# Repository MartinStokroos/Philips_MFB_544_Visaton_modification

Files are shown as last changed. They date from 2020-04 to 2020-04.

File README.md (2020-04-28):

# Squawker and Tweeter Modification for the Philips 544 MFB Speaker

This repository contains design information of 3D printable adapter parts to replace the original midrange and high frequency driver from the Philips 22RH544 MFB speaker with Visaton drivers. Feel free to fork this project to improve this modification proposal.

ORIGINAL 544 | MODIFIED 544 | BEST COMPROMISE
------------ | ------------ | ---------------
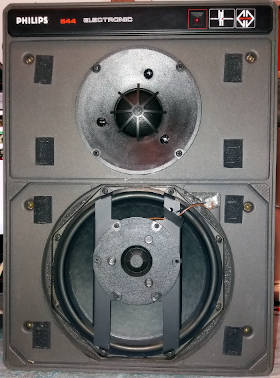
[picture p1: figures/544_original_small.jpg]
Philips 22RH544
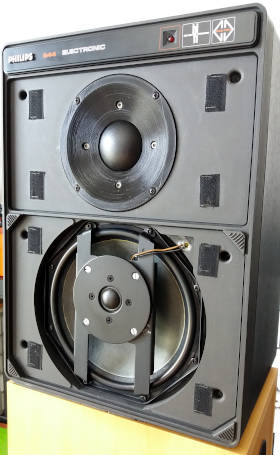
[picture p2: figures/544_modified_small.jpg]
Modified 544
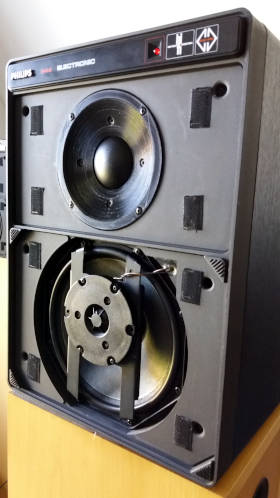
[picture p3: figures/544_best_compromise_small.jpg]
Best compromise 544
 |  | 

The following driver substitutes were selected because of their attractive price, quality and form-factor, which comes the closest to the original drivers:

PHILIPS | VISATON
------- | -------
Squawker AD0211/SQ8 | Visaton G 50 FFL dome midrange [1]
Tweeter AD0163/TE8 | Visaton G 20 SC dome tweeter [2]

## Why upgrading?
- The Philips AD0211/Sq8 squawker most often fails and a replacement must be found [3], [4].
- Overall improvement of the sound quality of the midrange and high frequencies.

## Conclusion
Attempt #3 seems the best compromise. It is the combination of the Visaton G50FFL soft dome midrange driver with the new baffle/horn design and the original Philips AD0163 tweeter. The provided solution solves the problem for a broken AD0211.
The frequency response is very close to the original. Minimal modifications of the electronics is needed in the 22RH544/50R. 

## Design for 3D-printed parts
Modification Attempt | openSCAD files | Remarks
-------------------- | -------------- | -------
 #1 | G50FFL_spacer_v1.scad G20SC_spacer_v1.scad | Mid driver sticks out above the baffle causing(?) a worse dip in the frequency reponse around 1.8kHz. The tweeter spacer does not need extra fixation holes to be drilled in the brackets. M4 hex-nuts can be pressed into the holes intended for mounting the tweeter on top of the spacer ring.  (3D-print with support on). The dust covers can not be put back, because the driver domes are sticking too far outside. 
 #2 | G50FFL_baffle_v1.scad G20SC_spacer_v2.scad | Attempt two with a new baffle/horn design for the G50FFL. (3D-print with support on). The dome is placed inwards to the original position of the AD0211 dome. The metal flange of the G50FFL must be removed by removing the four screws from the front side. The extra gasket, included with the G50FFL package, must be used between the driver and the new baffle/horn. The tweeter has been replaced by the G20SC and has been placed deeper inwards too. It is mounted with a 2mm spacer ring, leaving enough room for extreme woofer excursions. Fixation holes must be drilled in the brackets for mounting. The dust covers can be put back on. A small dip in the frequency response has been observed around the mid/high crossover frequency (~5kHz).
 #3 | G50FFL_baffle_v1.scad | The squawker AD0211 has been replaced by the G50FFL with the new baffle/horn design as in attempt #2. The original AD0136 tweeter has been restored.  The midrange frequencies around 1kHz are elevated a few dB's compared to the original. A minor modification in the electronics solves this problem.
Bonus | 544_capstand.scad | Capacitor mount, see pictures below. 

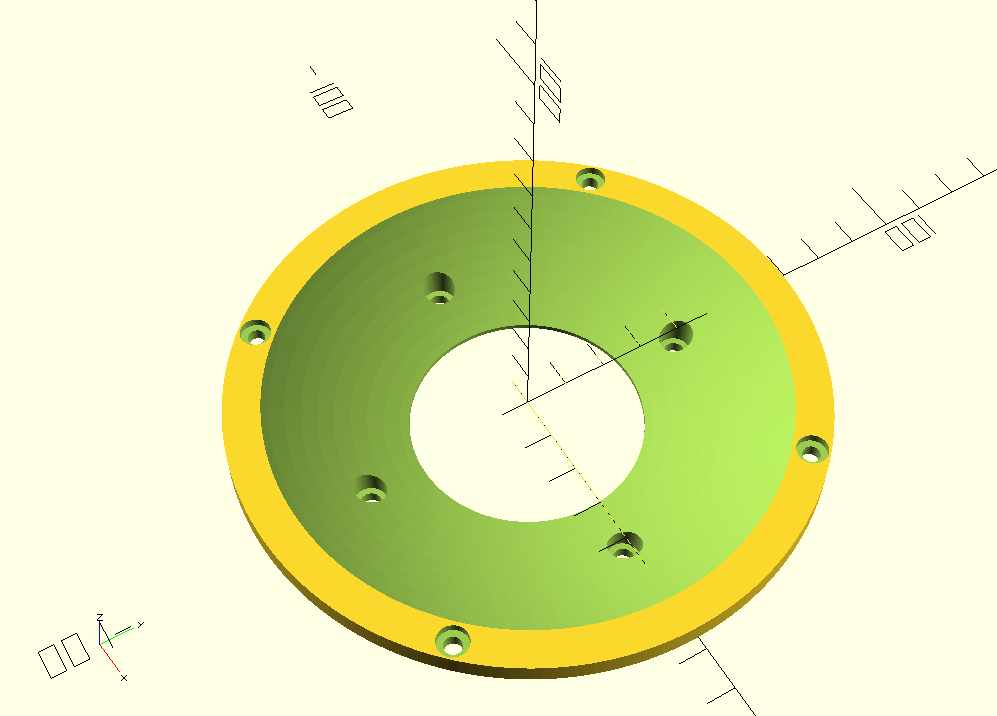
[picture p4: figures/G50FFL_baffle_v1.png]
new G50FFL baffle new G50FFL baffle_v1
# 

## Assembly
### G50FFL baffle
Push the washers (M4) into the holes. | Remove the flange from the Visaton G50FFL carefully.
------------------------------------ | ---------------------------------------------------
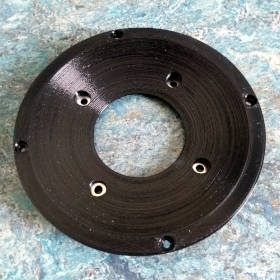
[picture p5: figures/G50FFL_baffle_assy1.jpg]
assy step 1
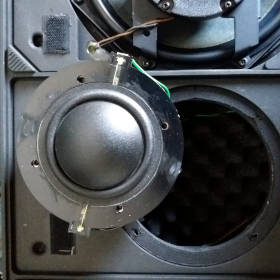
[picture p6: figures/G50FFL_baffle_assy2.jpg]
assy step 2
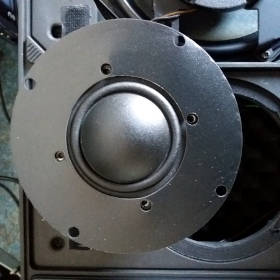
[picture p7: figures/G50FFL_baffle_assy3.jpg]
assy step 3
 |  | 

Place the spare gasket. | Mount the baffle and cutaway the redundant gasket material. Use M4*10mm screws with cylinder head.
---------------------- | ----------------------------------------------------------
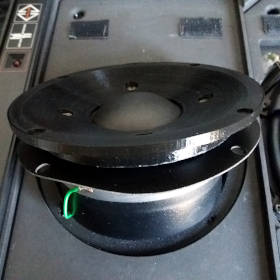
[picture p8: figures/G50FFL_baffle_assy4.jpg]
assy step 4
assy step 3 | 

| Mount the completed driver assembly. | 
| ----------------------------------- |
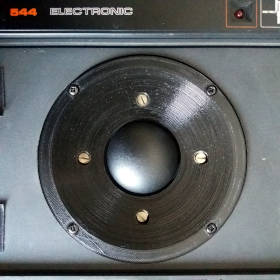
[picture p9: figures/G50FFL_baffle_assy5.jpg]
assy step 5
|  |

### Capacitor mount
BEFORE | AFTER
------ | -----
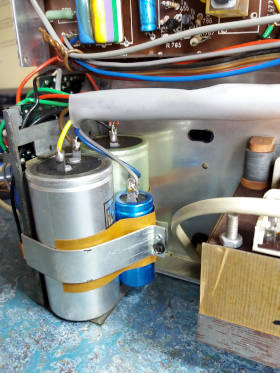
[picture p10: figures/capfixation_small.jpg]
original mount Capacitor fixation
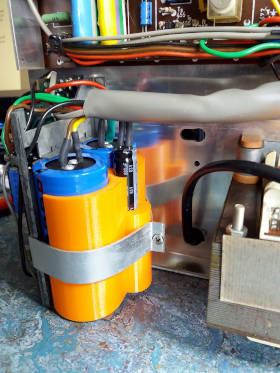
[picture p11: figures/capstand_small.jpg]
modified mount Capacitor stand
 | 
 
Recommended capacitors:

* C588, C535 = 4700 μF/63V, Vishay BCcomponents, 058/059 PLL-SI series aluminium capacitors, radial snap in 35 mm. (Conrad article #446251)
* C565 = 680 μF/40V, Panasonic EEU-FR1J681L series, radial 12.5 mm. (Conrad article #1476134)

## Modification of the electronics
To approach the original frequency response with modification attempt #3, the following changes should be made in the electronics of the 22RH544/50R:

* The frequency correction network consisting of R730 and C567 from the crossover network, should be disabled by removing R730.
* An L-pad network consisting of an 1.2 Ohms series resistor and a 47 Ohms parallel resistor should be placed between the crossover filter and the G50FFL driver (S405). This will add 1.5dB attenuation for the midrange.

| The 544 crossover network. In /50R, C568=3.3μF. |
| ----------------------------------------------- |
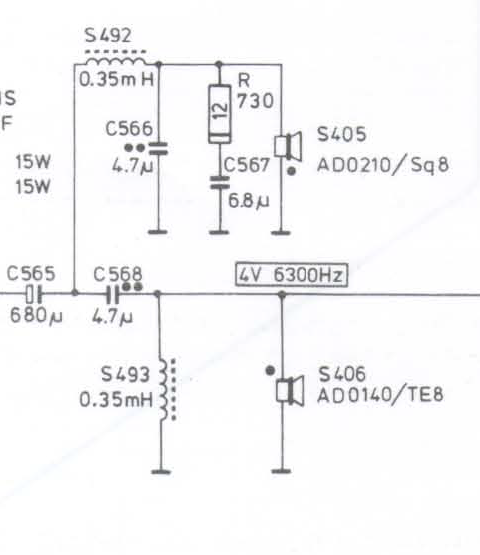
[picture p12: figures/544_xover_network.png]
544 crossover network
|  |
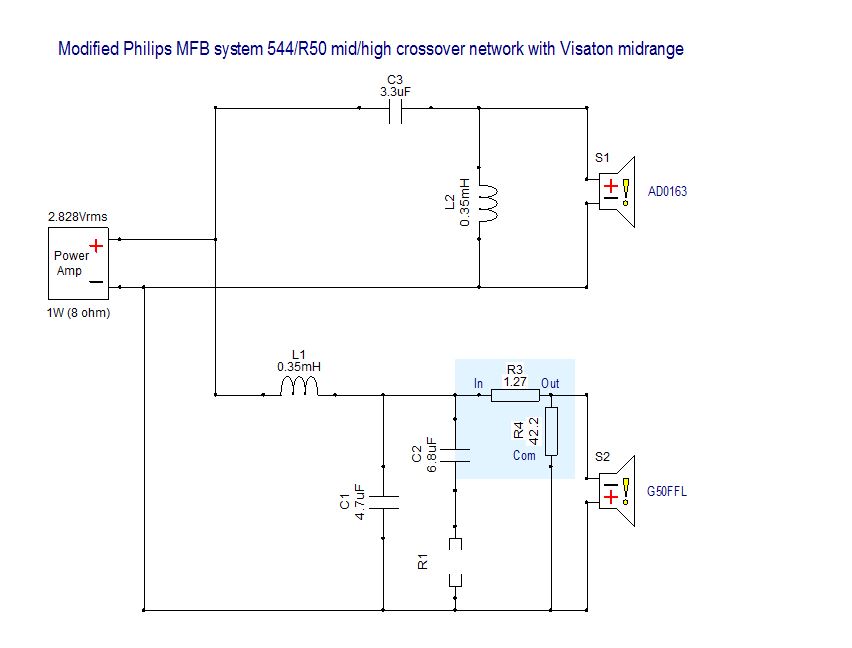
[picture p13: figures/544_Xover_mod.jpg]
Xover modification in Xsim
|  |

Simulations were performed with Xsim [5].

## Measurements
The frequency response measurements were carried out with the Behringer ECM 8000 calibration microphone [6] located at 30cm distance from the center of the speaker. From this distance, the individual response of the drivers already balances out and the influence of the room is minimal.
The frequency analyzer program that was used is Arta from Artalabs [7].

| Original 544 frequency response | 
| ------------------------------- |
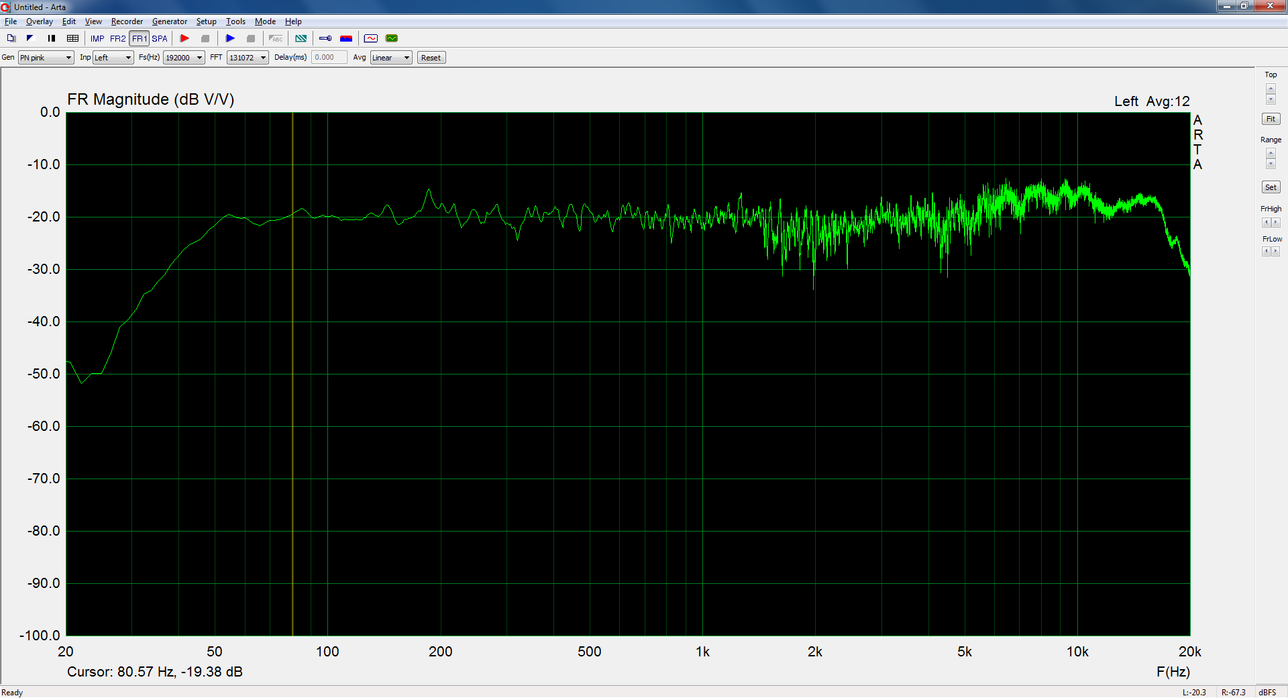
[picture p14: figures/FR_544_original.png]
Freq. response original 544
|  The boost in the high frequency range is remarkable. The reason for this could be the microphone. The factory datasheet of the ECM 8000 shows a somewhat elevated and rippled frequency response between 5kHz and 10kHz. |

| Frequency response attempt #2 | 
| ----------------------------- |
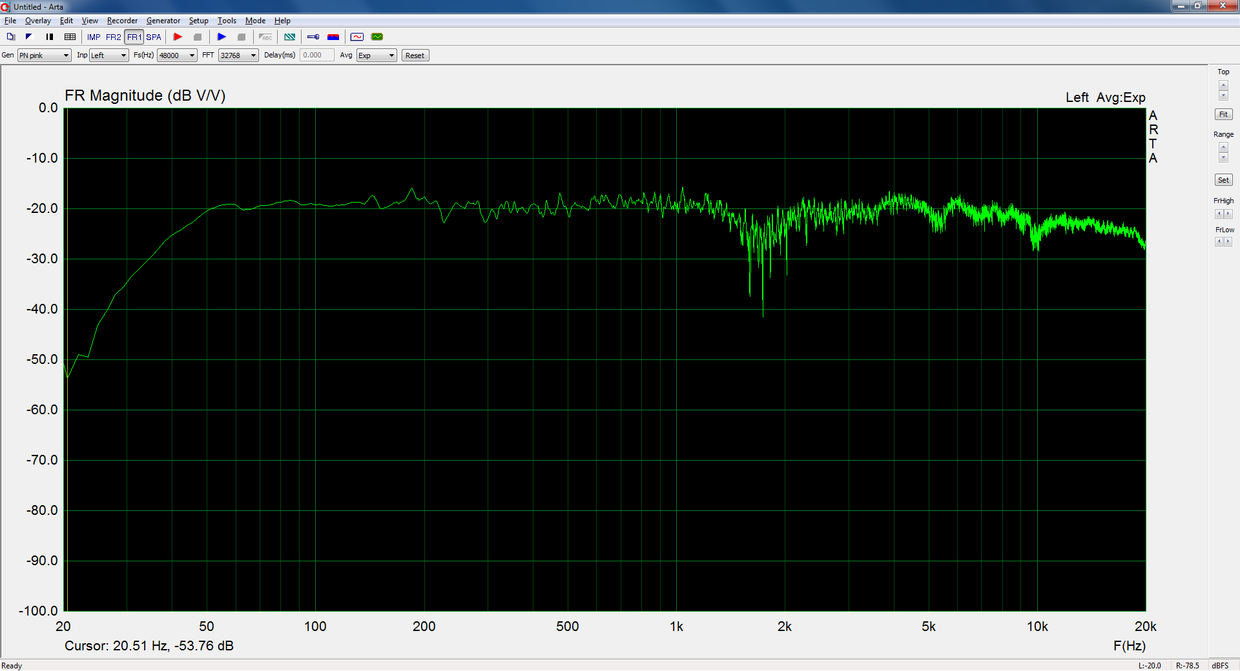
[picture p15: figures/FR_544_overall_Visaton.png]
Attempt #2 freq. response
|  A dominant frequency dip does appear around 1.8kHz and the G20SC starts rolling off from 9kHz (?) |
 
| Frequency response attempt #3 | 
| ----------------------------- |
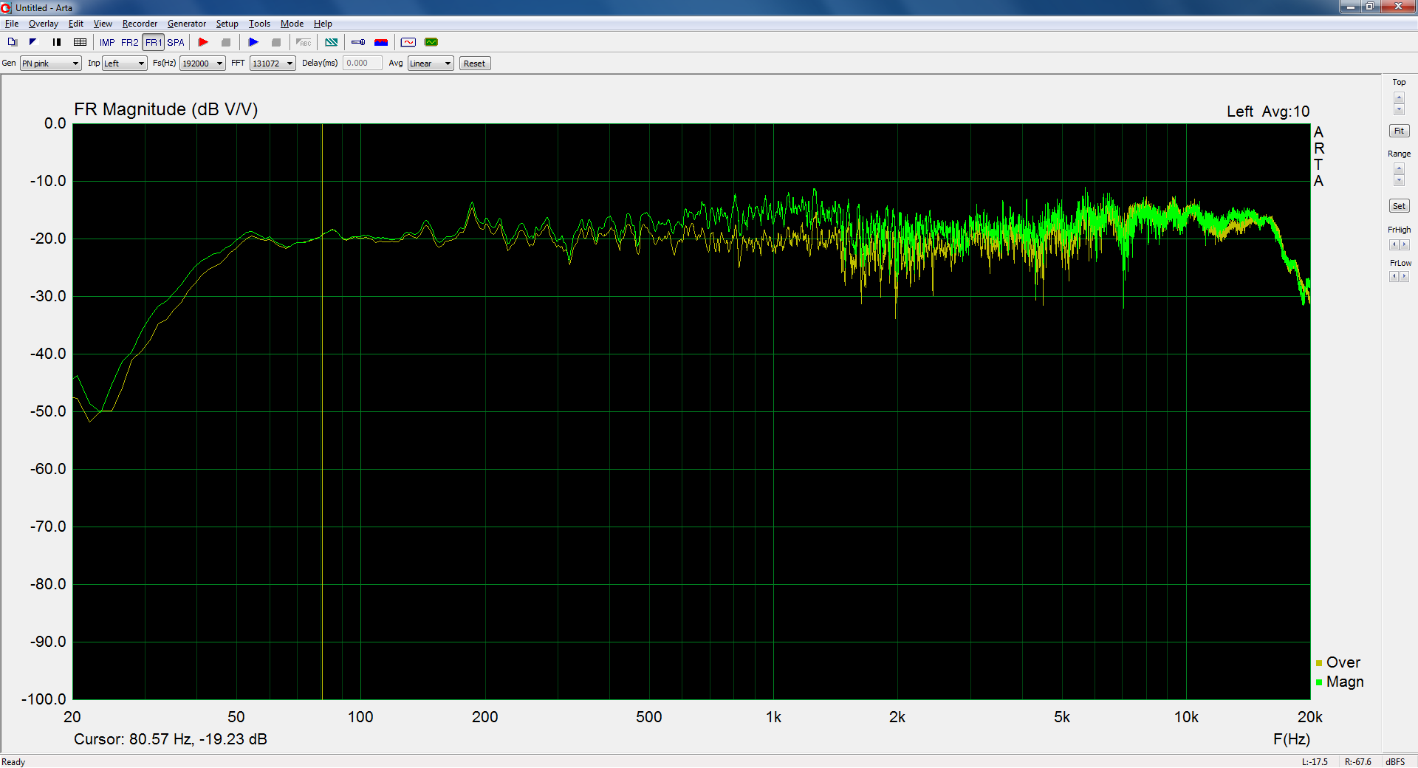
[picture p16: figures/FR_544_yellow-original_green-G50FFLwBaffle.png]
Attempt #3 freq. response, original electronics.
|  *Yellow trace: the original 544 frequency response, green trace: Visaton G50FFL midrange with new baffle/horn and Philips AD0163/TE8 tweeter, no modifications in the electronics.* A slight boost in the frequencies around 1kHz is noticeable. The midrange dominates. |
 
| Frequency response attempt #3, with modified electronics | 
| -------------------------------------------------------- |
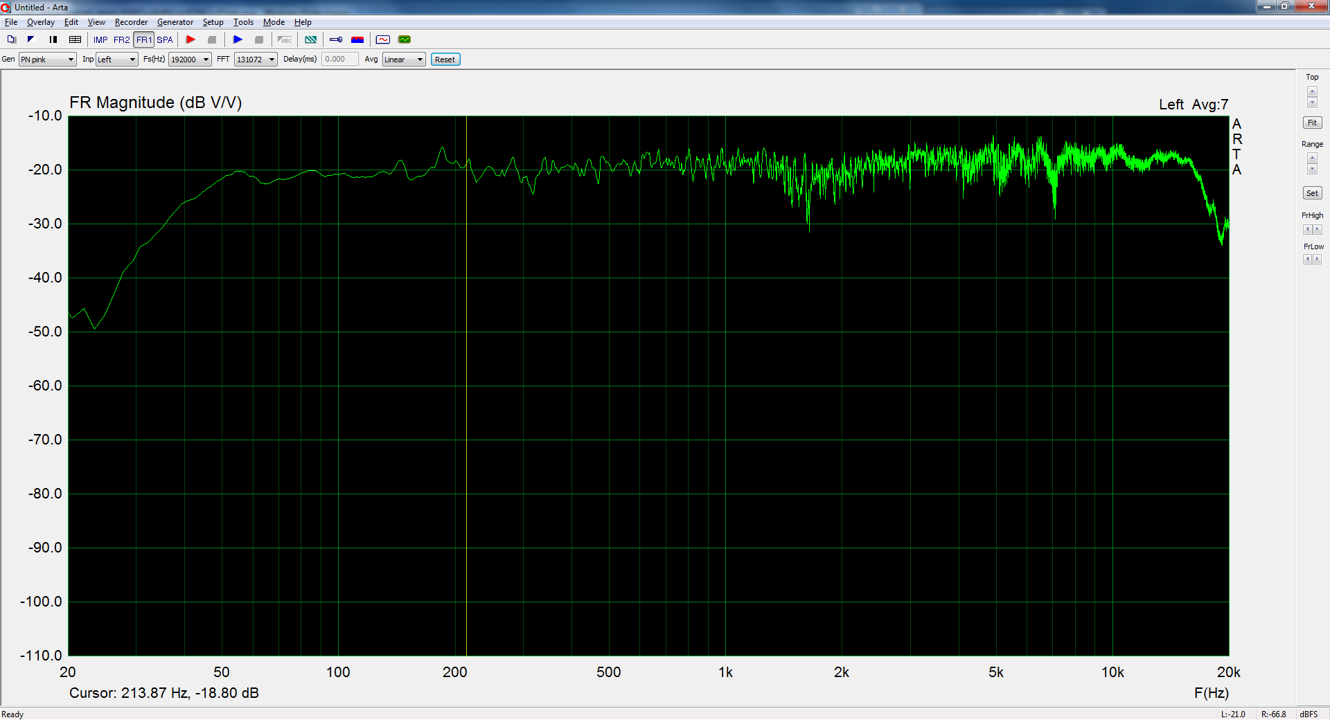
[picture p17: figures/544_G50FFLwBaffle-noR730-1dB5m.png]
Attempt #3 freq. response, and modifications in the electronics.
|  *Visaton G50FFL midrange with new baffle/horn design, original Philips AD0163/TE8 tweeter and modified electronics.* |

[1]: https://www.visaton.de/en/products/dome-midranges/g-50-ffl-8-ohm

[2]: https://www.visaton.de/en/products/dome-tweeters/g-20-sc-8-ohm

[3]: https://www.mfbfreaks.com/reparatie-en-service/tips-en-trucs/reparatie-middentoner-22ah587/
 
[4]: http://www.transistorforum.nl/forum/index.php?mode=thread&id=19335
 
[5]: http://libinst.com/ 
 
[6]: https://www.behringer.com/Categories/Behringer/Microphones/Condenser/ECM8000/p/P0118#googtrans(en|en)
 
[7]: http://www.artalabs.hr/

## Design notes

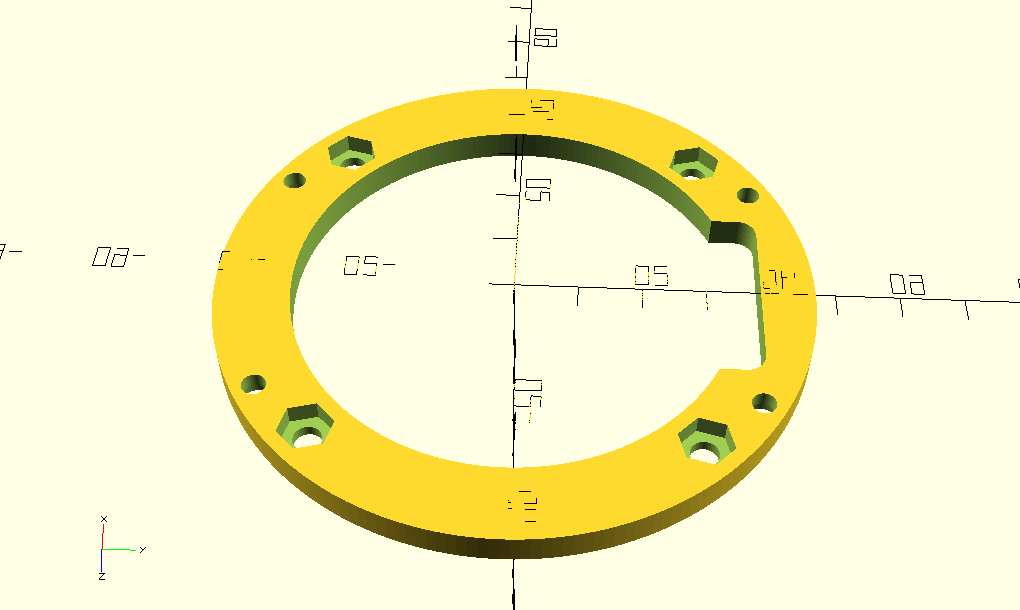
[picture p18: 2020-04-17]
figures/G20SC_spacer_v1.png

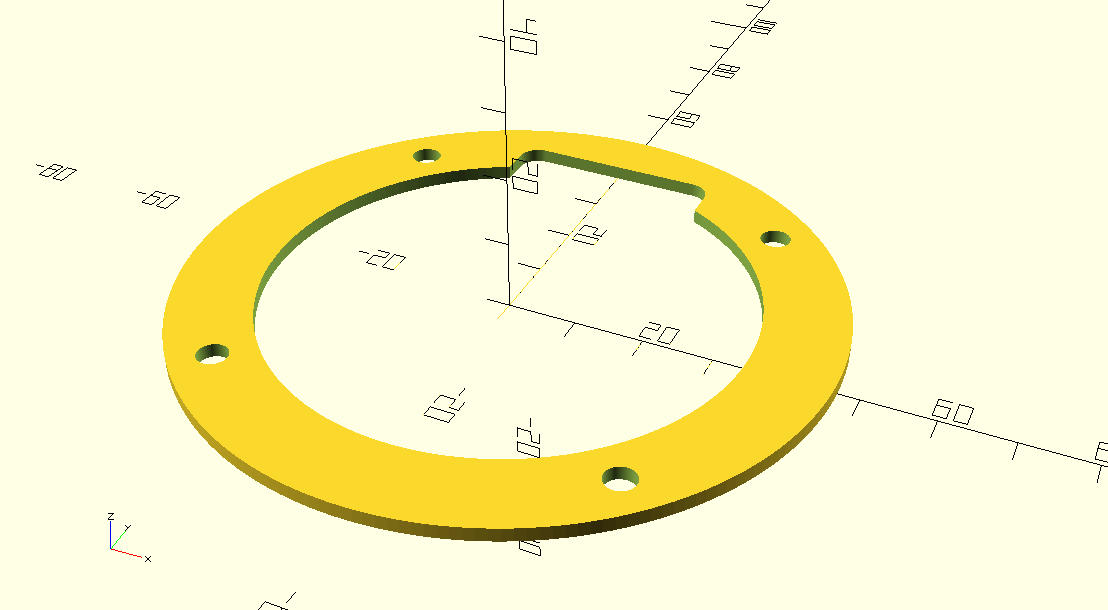
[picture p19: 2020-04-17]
figures/G20SC_spacer_v2.png

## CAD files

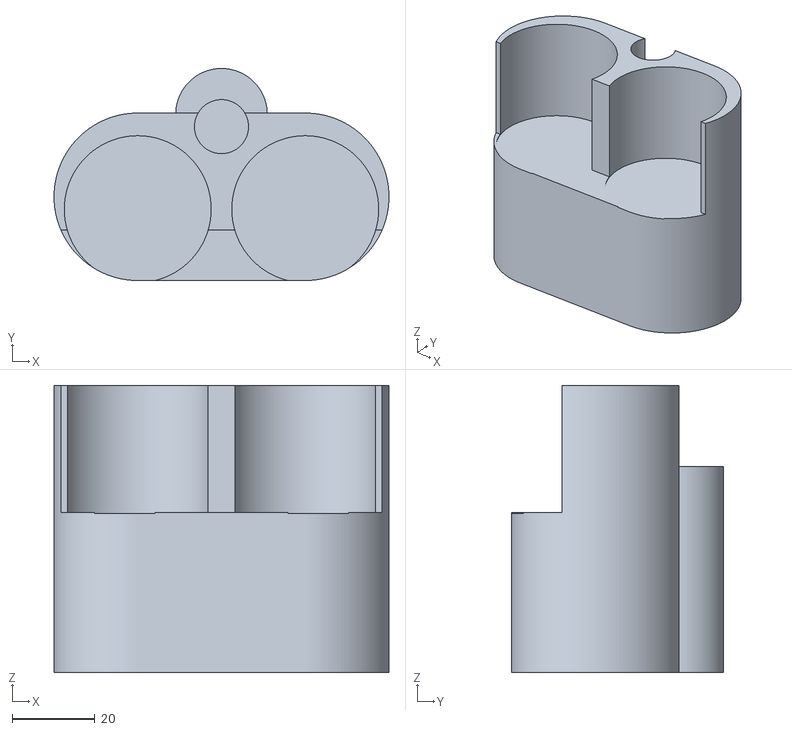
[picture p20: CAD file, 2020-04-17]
openscad/544_capstand.stl
81.2 x 51.4 x 69.6

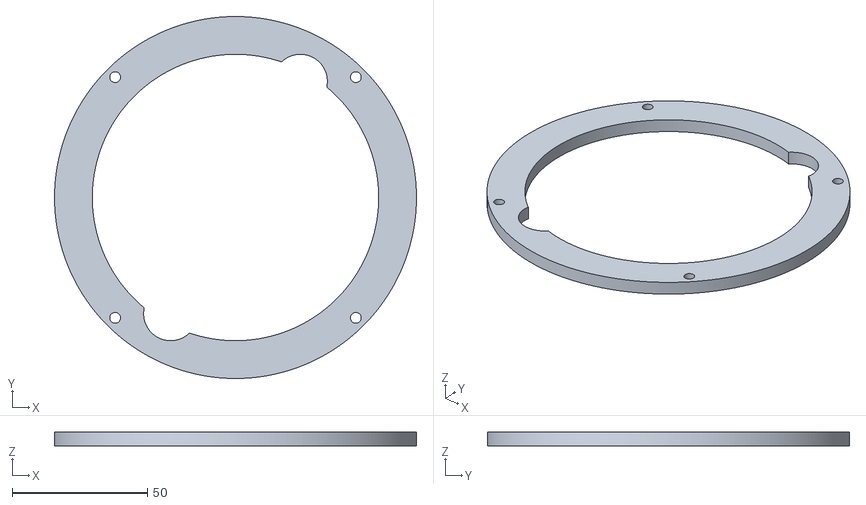
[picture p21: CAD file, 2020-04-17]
openscad/G50FFL_spacer_v1.stl
134.0 x 134.0 x 5.00

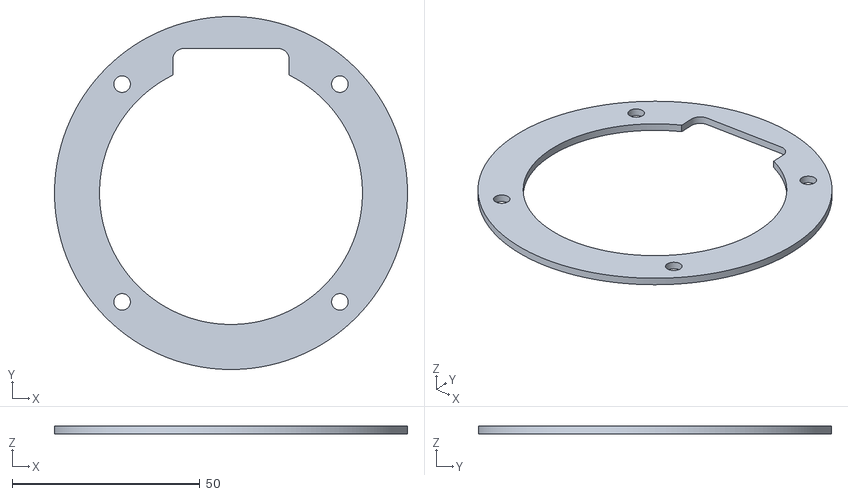
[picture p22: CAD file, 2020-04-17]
openscad/G20SC_spacer_v2.stl
94.0 x 94.0 x 2.00

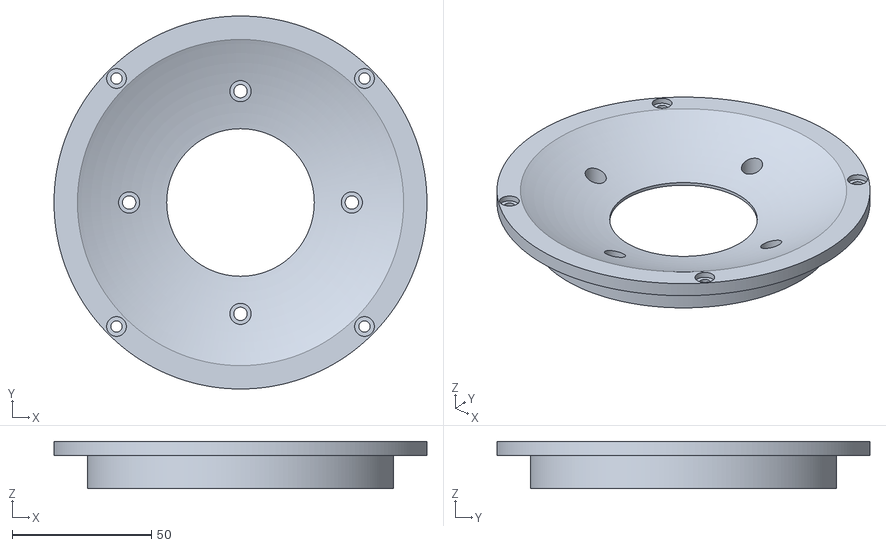
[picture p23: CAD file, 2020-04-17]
openscad/G50FFL_baffle_v1.stl
134.0 x 134.0 x 17.0

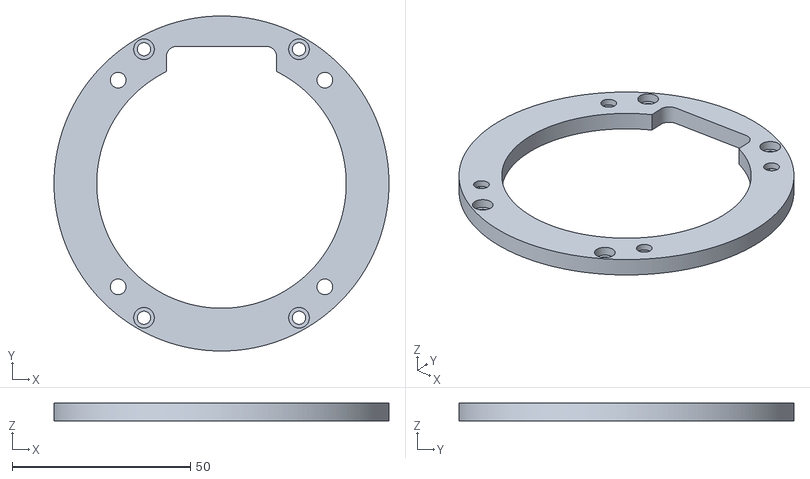
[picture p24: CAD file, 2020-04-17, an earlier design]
openscad/G20SC_spacer_v1.stl
94.0 x 94.0 x 5.00

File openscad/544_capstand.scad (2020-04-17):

// Quick-and-dirty sketch of a capacitor stand for the Philips 22RH544 MFB loudspeaker box. 

h = 79.6;
dc1=40.6; //diam. old 4700uF
dc2=35.6; //diam. new 4700uF
dc3=13.1; //diam. new 680uF
dc4=22.2; //diam. old 680uF
// All inner-diameters are oversized to compensate for the schrinkage.

difference() {
    union() {
        translate([dc1/2,0,0]) cylinder(d=dc1, h-10, center=false,$fn=150);
        translate([-dc1/2,0,0]) cylinder(d=dc1, h-10, center=false,$fn=150);
        translate([-dc1/2,-20.3,0])cube([dc1,dc1,h-10], center=false);
        translate([0,20,0]) cylinder(d=dc4, 50, center=false,$fn=200);
    }
            
    translate([dc1/2,-3,(h-41)]) cylinder(d=dc2, 41, center=false,$fn=150);
    translate([-dc1/2,-3,(h-41)]) cylinder(d=dc2, 41, center=false,$fn=150);
    translate([0,17,(h-35.5)])cylinder(d=dc3, 35.5, center=false,$fn=150);
            
    translate([-dc1,-28,h/2-1]) cube([2*dc1,20,h/2], center=false);   
    }

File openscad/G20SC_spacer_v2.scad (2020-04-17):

// Quick-and-dirty sketch for a plastic spacer to mount the Visaton G20SC Tweeter to the Philips 22RH544 MFB loudspeaker box.
// Revision 2

do = 94.0;
di = 70.0;
mnt_rad1 = 82/2; //tweeter
mnt_rad2 = 87/2; //brackets
thickness = 2.0;
d_screw1 = 4.4; //tweeter
d_screw2 = 3.7; //bracket
d_head = 5.8; //screw2 head size

difference() {
	cylinder(d=do, h=thickness, center=false,$fn=200);
    cylinder(d=di, h=12.0, center=true,$fn=200);
    
    // mounting holes tweeter
    translate([sqrt(pow(mnt_rad1,2)/2), sqrt(pow(mnt_rad1,2)/2) ,0]) cylinder(d=d_screw1, h=20.0, center=true,$fn=200);
    translate([-sqrt(pow(mnt_rad1,2)/2), sqrt(pow(mnt_rad1,2)/2) ,0]) cylinder(d=d_screw1, h=20.0, center=true,$fn=200);
    translate([sqrt(pow(mnt_rad1,2)/2), -sqrt(pow(mnt_rad1,2)/2) ,0]) cylinder(d=d_screw1, h=20.0, center=true,$fn=200);
    translate([-sqrt(pow(mnt_rad1,2)/2), -sqrt(pow(mnt_rad1,2)/2) ,0]) cylinder(d=d_screw1, h=20.0, center=true,$fn=200);
    
    // gap
    translate([0.0, 23 ,0]) roundCornersCube(31,31,20,3);
}




/*
http://codeviewer.org/view/code:1b36 
Copyright (C) 2011 Sergio Vilches
This program is free software: you can redistribute it and/or modify it under the terms of the GNU General Public License as published by the Free Software Foundation, either version 3 of the License, or (at your option) any later version.
This program is distributed in the hope that it will be useful, but WITHOUT ANY WARRANTY; without even the implied warranty of MERCHANTABILITY or FITNESS FOR A PARTICULAR PURPOSE. See the GNU General Public License for more details. You should have received a copy of the GNU General Public License along with this program. If not, see <http://www.gnu.org/licenses/>.
Contact: s.vilches.e@gmail.com


    ----------------------------------------------------------- 
                 Round Corners Cube (Extruded)                
      roundCornersCube(x,y,z,r) Where:                        
         - x = Xdir width                                     
         - y = Ydir width                                     
         - z = Height of the cube                             
         - r = Rounding radious                               
                                                              
      Example: roundCornerCube(10,10,2,1);                    
     *Some times it's needed to use F6 to see good results!   
 	 ----------------------------------------------------------- 
*/

module createMeniscus(h,radius) // This module creates the shape that needs to be substracted from a cube to make its corners rounded.
difference(){        //This shape is basicly the difference between a quarter of cylinder and a cube
   translate([radius/2+0.1,radius/2+0.1,0]){
      cube([radius+0.2,radius+0.1,h+0.2],center=true);         // All that 0.x numbers are to avoid "ghost boundaries" when substracting
   }

   cylinder(h=h+0.2,r=radius,$fn = 100,center=true);
}



module roundCornersCube(x,y,z,r)  // Now we just substract the shape we have created in the four corners
difference(){
   cube([x,y,z], center=true);

translate([x/2-r,y/2-r]){  // We move to the first corner (x,y)
      rotate(0){  
         createMeniscus(z,r); // And substract the meniscus
      }
   }
   translate([-x/2+r,y/2-r]){ // To the second corner (-x,y)
      rotate(90){
         createMeniscus(z,r); // But this time we have to rotate the meniscus 90 deg
      }
   }
      translate([-x/2+r,-y/2+r]){ // ... 
      rotate(180){
         createMeniscus(z,r);
      }
   }
      translate([x/2-r,-y/2+r]){
      rotate(270){
         createMeniscus(z,r);
      }
   }
}

// Helper to create 3D text with correct font and orientation
module t(t, s = 18, style = "") {
  rotate([90, 0, 0])
    linear_extrude(height = 1)
      text(t, size = s, font = str("Liberation Sans", style), $fn = 16);
}

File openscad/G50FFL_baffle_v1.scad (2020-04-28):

// Quick-and-dirty design sketch for a new plastic baffle for the Visaton G50FFL, which meets the form-factor of the AD0211 Squawker.
// Revision 1.2

do = 134.0; // diameter AD0211
di = 110; //cutout cabinet
thickness = 5.0; //ring

mnt_rad = 126/2;
depth = -12.0; //depth of the driver behind the baffle

d_screw1 = 4.0;
d_head1 = 7.1;

d_dome_bot = 66.67;
d_dome_top = 54.0; //53.0 in rev. 1.0
d_screw2 = 4.8;
d_head2 = 9.4; // Rev. 1.2, better fit for washer.

h_dome = 3.9; //rev. 1.0, space between suspension and rim changed from 3.8 to 3.9.
r_sphere = 123; //122 with rev. 1.0
sphere_offs = r_sphere-10.0;

difference() {
	union() {
        cylinder(d=do, h=thickness, center=false,$fn=200);
        translate([0, 0, depth]) cylinder(d=di, h=12.1, center=false,$fn=200);
    }
    
    // mounting holes
    translate([sqrt(pow(mnt_rad,2)/2), sqrt(pow(mnt_rad,2)/2) ,0]) cylinder(d=d_screw1, h=12.0, center=true,$fn=200);
    translate([-sqrt(pow(mnt_rad,2)/2), sqrt(pow(mnt_rad,2)/2) ,0]) cylinder(d=d_screw1, h=12.0, center=true,$fn=200);
    translate([sqrt(pow(mnt_rad,2)/2), -sqrt(pow(mnt_rad,2)/2) ,0]) cylinder(d=d_screw1, h=12.0, center=true,$fn=200);
    translate([-sqrt(pow(mnt_rad,2)/2), -sqrt(pow(mnt_rad,2)/2) ,0]) cylinder(d=d_screw1, h=12.0, center=true,$fn=200);
    
    translate([sqrt(pow(mnt_rad,2)/2), sqrt(pow(mnt_rad,2)/2) ,thickness-2.0]) cylinder(d=d_head1, h=10.0, center=false,$fn=200);
    translate([-sqrt(pow(mnt_rad,2)/2), sqrt(pow(mnt_rad,2)/2) ,thickness-2.0]) cylinder(d=d_head1, h=10.0, center=false,$fn=200);
    translate([sqrt(pow(mnt_rad,2)/2), -sqrt(pow(mnt_rad,2)/2) ,thickness-2.0]) cylinder(d=d_head1, h=10.0, center=false,$fn=200);
    translate([-sqrt(pow(mnt_rad,2)/2), -sqrt(pow(mnt_rad,2)/2) ,thickness-2.0]) cylinder(d=d_head1, h=10.0, center=false,$fn=200);
    
    // dome cut out
    cylinder(d=d_dome_top, h=30, center=true,$fn=200);
    translate([0, 0, -10+depth+h_dome]) cylinder(d=d_dome_bot, h=10, center=false,$fn=200);
    translate([0, 0, sphere_offs]) sphere(r_sphere, $fn=300);
    
    //G50FFL holes
    translate([40, 0, 0]) cylinder(d=d_screw2, h=30.0, center=true,$fn=200);
    translate([0, 40, 0]) cylinder(d=d_screw2, h=30.0, center=true,$fn=200);
    translate([-40, 0, 0]) cylinder(d=d_screw2, h=30.0, center=true,$fn=200);
    translate([0, -40, 0]) cylinder(d=d_screw2, h=30.0, center=true,$fn=200);
    
    translate([40, 0, depth+3.0]) cylinder(d=d_head2, h=30.0, center=false,$fn=200); // rev. 1.2, changed depth offset from 2.8 to 3.0
    translate([0, 40, depth+3.0]) cylinder(d=d_head2, h=30.0, center=false,$fn=200);
    translate([-40, 0, depth+3.0]) cylinder(d=d_head2, h=30.0, center=false,$fn=200);
    translate([0, -40, depth+3.0]) cylinder(d=d_head2, h=30.0, center=false,$fn=200);
}

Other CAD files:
openscad/G50FFL_spacer_v1.scad
openscad/G20SC_spacer_v1.scad

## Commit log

2020-04-17 readme+baffle design update
    [G50FFL_baffle_v1.scad]
2020-04-19 add assembly details
2020-04-27 added modification schematic
2020-04-28 update baffle rev 1.2
    [G50FFL_baffle_v1.scad]
2020-04-28 update readme - screw info
